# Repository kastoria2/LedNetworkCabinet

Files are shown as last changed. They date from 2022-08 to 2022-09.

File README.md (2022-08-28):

# What is in this project

These are the prototype resources for the "LED Network Cabinet".  It includes
- 3D printed honeycomb / "hexagon grid" cabinet panel
  - About 2 feet x 2 feet
  - Backlit with RGB LED strip
- "Arduino" firmware source code for running the LED animations.
  - Written in the Arduino IDE.  Should support many microcontrollers that the IDE supports
  - Prototype used [Teensy 2.0](https://www.pjrc.com/store/teensy.html)
- "Arduino" project for a LED strip tester
  - I hand wired LED strips in rows of 7.  I used the strip tester to check each row as I went.
- Python & QT based firmware generator and animation tester
  - It is helpful to have the physical coordinates for the LEDs for animations.  This tool generates those coordinates so they can be pasted into the Arduino IDE
  - Also has basic LED animation simulator.  So you can test out new animations easily in Python before moving them to Arduino/C.
  
# Before you start!

This is a prototype that got too successful.  I was planning to just make 2 tiles to test how
- the tiles glued together
- the backlight looked
- the opaque hexagons fit into the tiles

It all worked out well enough that I just kept printing.  The plan was to figure everything out as I went.  So there is a good amount of cobbling used to 'finish' the project.

# Required skills/tools

- Basic crafting skills
  - gluing
  - cutting small wooden boards
  - attaching items with screws
  - etc
- 3D printer and slicer
- Soldering iron, solder, soldering skills, etc
- Use Arduino IDE to compile a sketch to a microcontroller

# Construction!!

Checkout [the wiki](https://github.com/kastoria2/LedNetworkCabinet/wiki)

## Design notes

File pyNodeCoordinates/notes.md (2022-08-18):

2022-08-01
    - You have the Python "Hexagon Panel" wired into QML.
    - Need to expose Python Property so QML can access them.

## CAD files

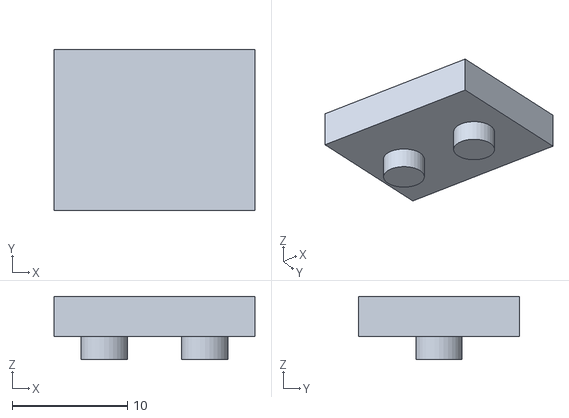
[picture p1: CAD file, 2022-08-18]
3d_print/connector_02.stl
17.4 x 14.0 x 5.50

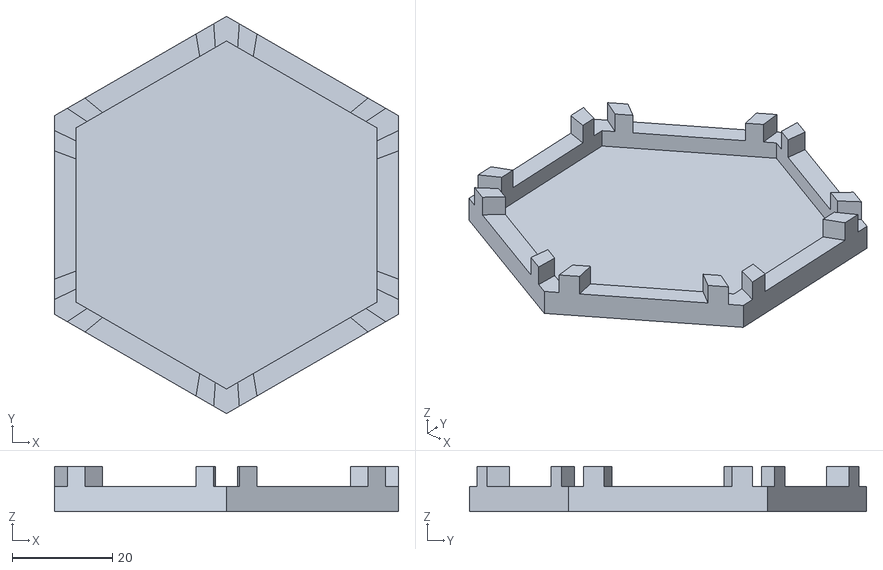
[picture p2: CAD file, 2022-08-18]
3d_print/cap_02.stl
68.8 x 79.4 x 9.00

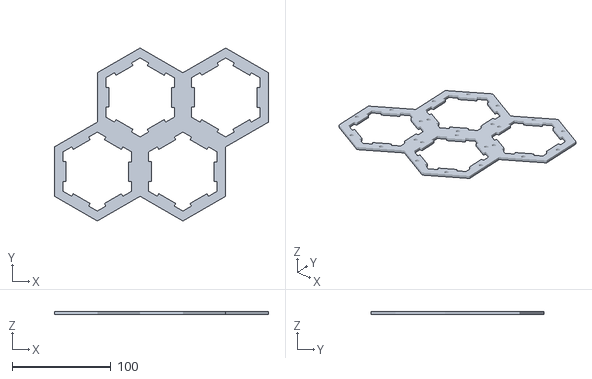
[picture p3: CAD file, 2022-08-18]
3d_print/backlight_02.stl
216.5 x 175.0 x 3.00

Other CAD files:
3d_print/backlight_02.blend

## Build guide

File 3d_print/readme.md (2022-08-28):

# Design

The design was done in Blender 2.90.0.  I needed something more powerful than Tinkercad and didn't want to buy&learn Fusion 360.
The 'panel' is comprised of 3 parts.
- Semi-transparent 'backlight' tiles
  - These are most of what the 'panel' is made of
  - Diffuse the LED light a bit
- Opaque Cap
  - These are the 'hexagons' that go into the panel
- Connectors
  - Small tabs used to reinforce the connection between tiles when you glue them together

The .blend file containes all three parts modeled in it.  They are partly generated with modifiers like 'arrays' and such.  I've forgotten the details of what I did in here.  But to get the separate STL files, I just selected the pieces I needed from the .blend.  The STL export has the capability to export just selected items.  That's how I 'split' the design into separate files

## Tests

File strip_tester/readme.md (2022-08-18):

2022-08-07
    - Have a 'breath' animation working.  But the colors are hard-coded to a the [0] LED.
    - Don't have a mapping from index [0, 98) to the strip locations.

2022-07-28
I have 2 strips of 49 LEDs each assembled and tested.
Raw data on current draws for a strip of 49 LEDs

All current draws in mA
- Intensity 8
    - r 45.5
    - g 45.5
    - b 45.5
- Intensity 16
    - r 60.9
    - g 60.9
    - b 60.9
- Intesnity 32
    - r 91.8
    - g 91.8
    - b 91.8
- Intensity 64
    - r 156.8
    - g 156.8
    - b 156.8
- Intensity 128
    - r 220
    - g 190
    - b 180
- Intensity 255
    - r 247
    - g 214
    - b 200

2022-07-09

I was building the hexagon panel.  I hand-wired the LED by rows with 7 LEDs in them.  This program just cycles though some colors turning on each LED in turn.  Basically testing that there are no shorts or defective LEDs in the strip.

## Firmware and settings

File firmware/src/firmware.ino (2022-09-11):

#include <Adafruit_NeoPixel.h>

#include "LedLocations.h"
#include "HexPanel.h"
#include "Animation/Animations.h"

#include "WebService.h"

#ifdef __AVR__
  #include <avr/power.h>
#endif

#define BRIGHTNESS 16
#define PIN 6

HexPanel hexPanel(625, 736);
NeoPixels pixels(NUM_LEDS, PIN, NEO_GRB + NEO_KHZ800);
Animations animations(hexPanel, NUM_LEDS);

void setup() {

#if defined(__AVR_ATtiny85__) && (F_CPU == 16000000)
  clock_prescale_set(clock_div_1);
#endif
  // END of Trinket-specific code.

  Serial.begin(9600);

  pixels.begin(); // INITIALIZE NeoPixel strip object (REQUIRED)
  pixels.setBrightness(BRIGHTNESS);

  initWebService(&animations);
}

void loop() {

  // updateAnimation(inputParams, leds);
  animations.update();
  
  for(int i = 0; i < NUM_LEDS; i++)
  {
    pixels.setPixelColor(i, hexPanel.getLedStrip()[i].color);
  }
  pixels.show();

  updateWebService();
}

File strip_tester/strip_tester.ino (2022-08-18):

// NeoPixel Ring simple sketch (c) 2013 Shae Erisson
// Released under the GPLv3 license to match the rest of the
// Adafruit NeoPixel library

#include <Adafruit_NeoPixel.h>
#ifdef __AVR__
 #include <avr/power.h> // Required for 16 MHz Adafruit Trinket
#endif

// Which pin on the Arduino is connected to the NeoPixels?
#define PIN        6 // On Trinket or Gemma, suggest changing this to 1

// How many NeoPixels are attached to the Arduino?
#define NUMPIXELS 98 // Popular NeoPixel ring size

// When setting up the NeoPixel library, we tell it how many pixels,
// and which pin to use to send signals. Note that for older NeoPixel
// strips you might need to change the third parameter -- see the
// strandtest example for more information on possible values.
Adafruit_NeoPixel pixels(NUMPIXELS, PIN, NEO_GRB + NEO_KHZ800);

#define DELAYVAL 32 // Time (in milliseconds) to pause between pixels

void setup() {
  // These lines are specifically to support the Adafruit Trinket 5V 16 MHz.
  // Any other board, you can remove this part (but no harm leaving it):
#if defined(__AVR_ATtiny85__) && (F_CPU == 16000000)
  clock_prescale_set(clock_div_1);
#endif
  // END of Trinket-specific code.

  pixels.begin(); // INITIALIZE NeoPixel strip object (REQUIRED)
}

#define INTENSITY 8
#define NUM_COLORS 5
uint32_t COLORS[NUM_COLORS] = {
  pixels.Color(INTENSITY, 0, 0),
  pixels.Color(0, INTENSITY, 0),
  pixels.Color(0, 0, INTENSITY),
  pixels.Color(INTENSITY, 0, INTENSITY),
  pixels.Color(INTENSITY, INTENSITY, INTENSITY)  
};

void loop() {

  for(int j = 0; j < NUM_COLORS; j++)
  {
    pixels.clear(); // Set all pixel colors to 'off'
  
    // The first NeoPixel in a strand is #0, second is 1, all the way up
    // to the count of pixels minus one.
    for(int i=0; i<NUMPIXELS; i++) { // For each pixel...
  
      // pixels.Color() takes RGB values, from 0,0,0 up to 255,255,255
      // Here we're using a moderately bright green color:
//      if(i < 16)
//      {
        pixels.setPixelColor(i, COLORS[j]);
//      }
//      else
//      {
//        pixels.setPixelColor(i, pixels.Color(0,0,0));
//      }
  
      //pixels.show();   // Send the updated pixel colors to the hardware.
  
      //delay(DELAYVAL); // Pause before next pass through loop
    }
    pixels.show();
    delay(3000);
  }
}

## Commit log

2022-08-18 Initial commit of the code that tests 7-segment LED strips.
2022-08-18 - Python model of the hex panel and hexagons. - Some unit tests for them - Basic framework for using the Python hex code in QML.
2022-08-18 98 LEDs at 8 for testing.
2022-08-18 - Wiring Python QObjects into QML instead of the JS implementation.
2022-08-18 - Accessors to wire Hexagon as the model into QML.
2022-08-18 - Starting to find vertices with valid LEDs - Removing generating project files from git.
2022-08-18 - Drawing the LEDs in the correct locations, filtered to 'interior' vertices. - Better separation between the python model coordinate space and the projection into raste/qml space.
2022-08-18 - Initial code for animation framework.
2022-08-18 - Panel keeps a 'led strip' that matches the physical led strip. - Using panel 'led strip' instead of the global.
2022-08-18 - Animation that lights up LEDS in index order. - Testing that the ledStrip is indexed correctly.
2022-08-18 - PoC animation using LED distance from a point as an input parameter.
2022-08-18 - LedOut positions are in um only. - Working on getting animation code to be in um with int math.
2022-08-18 - Initial port of prototype Python code into C++ firmware. - Using float math. Doesn't seem to be a performance issue.
    [firmware.ino]
2022-08-18 - Generate C++ firmware definitions for the leds.
2022-08-18 - Initial impl of the radiate animation - Using generated LED locations in firmware.
2022-08-18 - Initial work to add the 3d files and some documentation to the project.
    [backlight_02.blend, backlight_02.stl, cap_02.stl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]
2022-08-28 - PoC for running on ESP32 S2 - Connected to local WiFi - Running a basic web server - Accepting GET requests - Reading GET query parameters - Updating LED color based on query params - Refactoing co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
2022-09-03 - Migrated project to VS Code/Platform IO. Arduino IDE was getting frustrating.
2022-09-03 - Moved order to match initializer list in LedLocations.h. The initlists were actually assigning the uint32_t 'color' to the 'distance' param b/c they rely on member order in the struct.
2022-09-08 - Refactor to have /api/v1/status to tell the current animation and settings. - Post to /api/v1/status to update colors. - Might want to rethink this. Might want to post all settings to the '../anima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
2022-09-10 - Show selectable list of Animations from the server. - Select the current animation by default.
2022-09-11 - An 'Animation' update functions on an entire HexPanel rather than individual Led objects.
2022-09-12 - Actually adding the TwinkleAnimation code.... - Ensures that twinkles are assigned to unique leds.
